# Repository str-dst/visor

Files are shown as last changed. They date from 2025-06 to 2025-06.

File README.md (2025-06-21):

# The digital face of unit 0x4C6F75

Visor based on a cheap modified 3M 6800 clone full face gas mask

## What?

Two "see-through" 16x16 ws2812b LED panels mounted behind the glass of a full face gas mask.
The glass was tinted using Rit-Dyemore Graphite-Black plastic dye to hide the electronics inside.  

The panels are controlled by a relatively simple Python script running on a RPi Zero 2W.  
A wired six-button remote strapped to my left hand is used to change the displayed faces.  
Two of the buttons on the remote act as "modifiers", making a total of 16 combinations possible.  

## How?

The faces are stored as simple 16x32 1-bit black/white bitmap files.  
Every face is mapped to one of the remotes keycodes.  

The image files are first loaded with PIL and the pixel values are stored in a list.  
A preselect color is then added to the "active" white pixels of the loaded image.  
The list of pixel values is then simply displayed on the LED matrix.  

The remote controller is based on an Elite-C controller and hardwired to the Pi via USB.  
For each keypress or keypress-combination a distinctive keycode is sent over a serial connection.  
On key release the code '0x00' is sent, though this has currently no real use.  

Keycode 0x10 is an exception and cycles through different colors for the face.  
Some faces have a preset color that changes automatically for an added effect.  

## Currently implemented codes

 |Keycode|Display content|Color|
 |-|-|-|
 |0x01|Happy, pointy upwards|default|
 |0x02|Wide round eyes|default|
 |0x03|Sleepy drowsy looking|default|
 |0x04|Wink, left eye closed|default|
 |0x05|BOOPED, pointy inward|default|
 |0x06|Dizzy, twirly eyes|purple|
 |0x07|Annoyed, Flat eyes|default|
 |0x08|Focused, Small eyes|default|
 |0x09|Love, Heart eyes|pink|
 |0x0A|Dead, X eyes|red|
 |0x0B|Angry, frowning|red|
 |0x0C|Sad, droopy|blue|
 |0x0D|Text: BEEP|green|
 |0x0E|Text: awoo|orange|
 |0x0F|Text: NO|red|

## Possible additions / changes for the future

 - Add more key combos to the remote to be able to add more faces
 - Make it possible to create "compound faces" individually controlling the left or right eye
 - Adding a "boop sensor" to the nose of the mask
 - A microphone on the inside of the mask and a speaker on the outside for real-time voice changing
 - Eye detection inside the mask to automatically change the face / display a "blink" animation

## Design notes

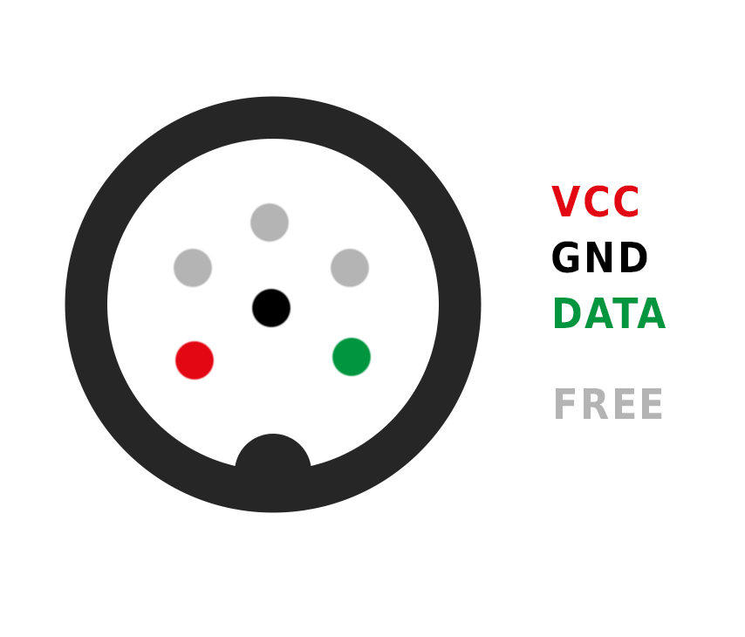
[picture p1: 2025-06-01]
gx12_pinout.png

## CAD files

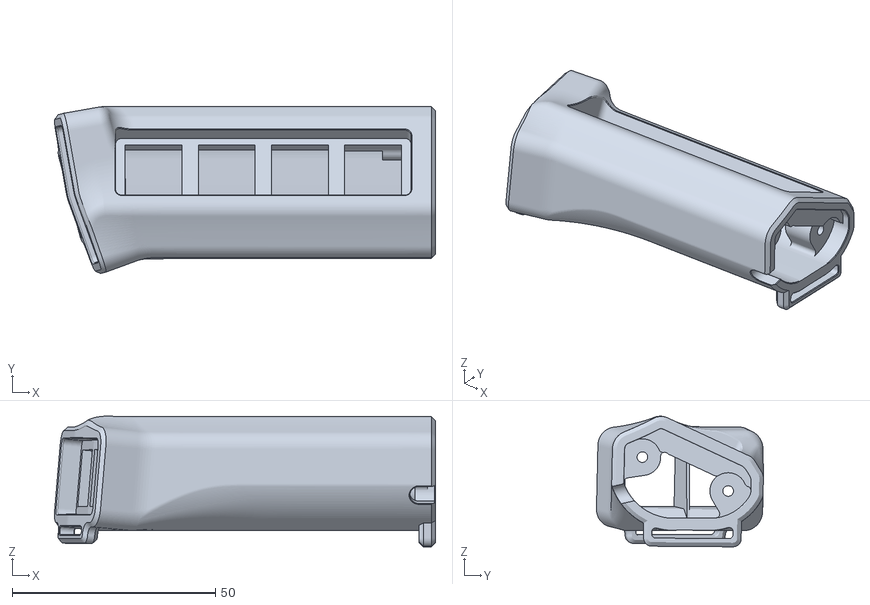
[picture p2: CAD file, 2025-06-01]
stls/remote_body.stl
93.7 x 41.1 x 32.1

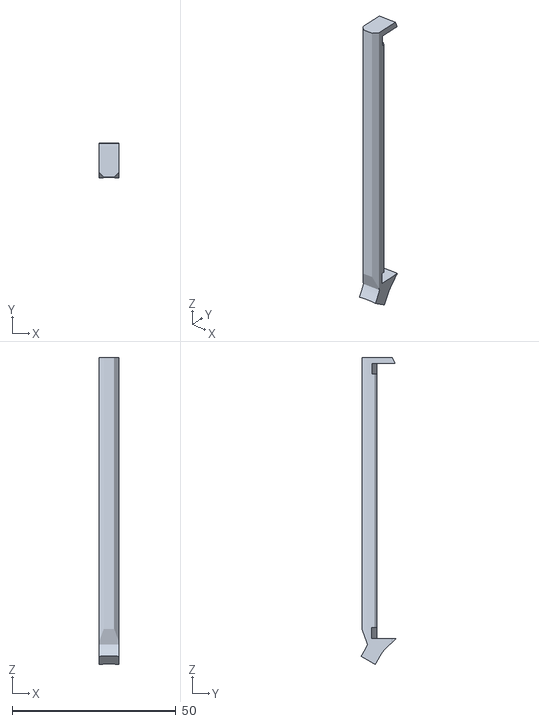
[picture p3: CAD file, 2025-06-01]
stls/display_center_support.stl
6.00 x 10.6 x 93.9

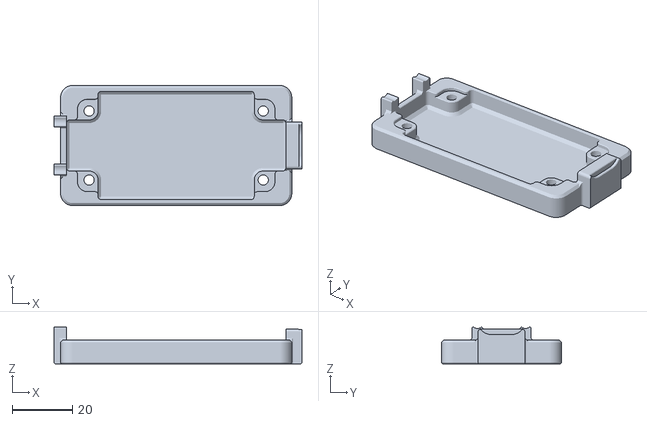
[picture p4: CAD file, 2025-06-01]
stls/rpi_case_bottom.stl
82.6 x 40.0 x 12.3

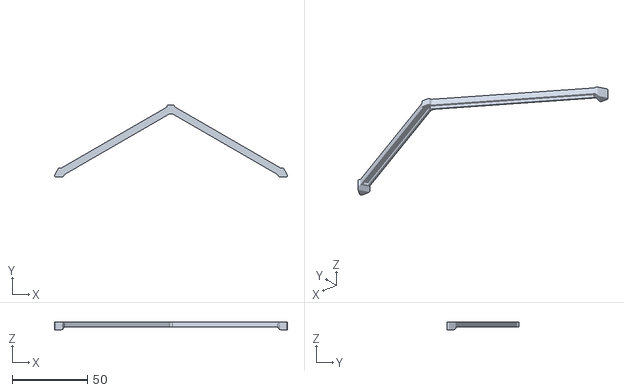
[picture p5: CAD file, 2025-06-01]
stls/display_top_frame.stl
154.7 x 48.1 x 5.00

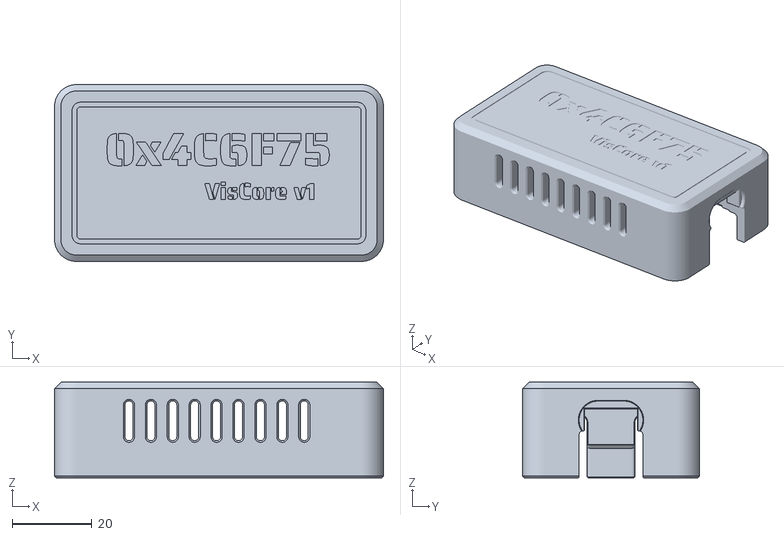
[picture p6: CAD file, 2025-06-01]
stls/rpi_case_top.stl
82.6 x 44.4 x 24.0

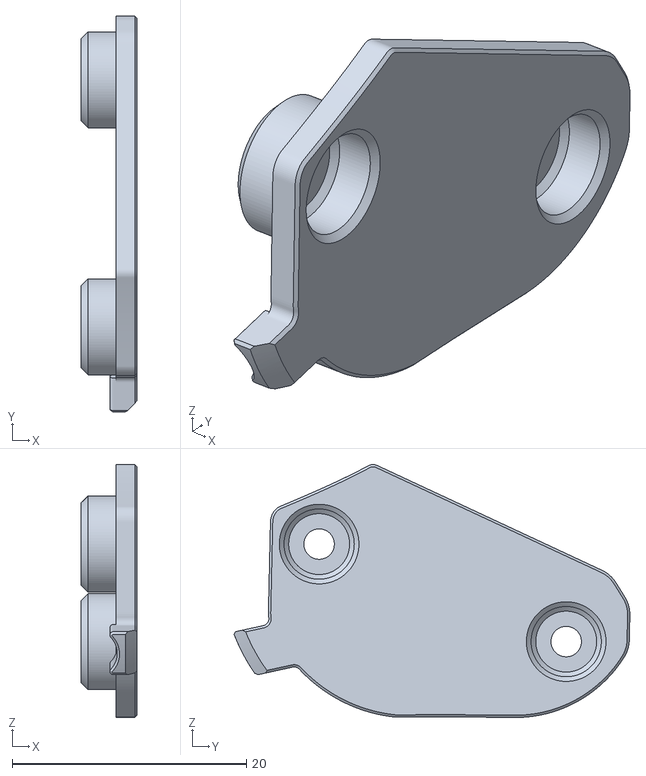
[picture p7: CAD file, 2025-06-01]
stls/remote_lid.stl
4.80 x 33.8 x 21.6

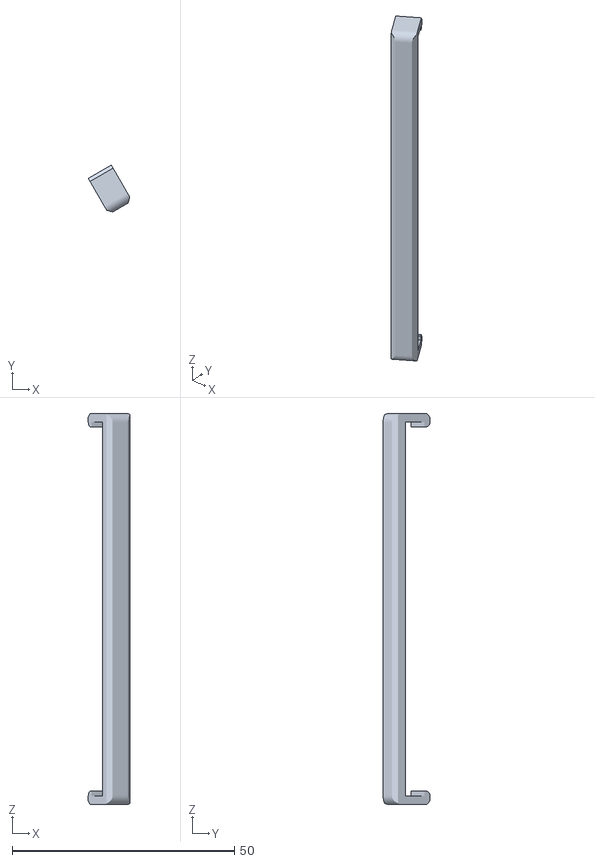
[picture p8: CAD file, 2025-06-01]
stls/display_side_brace.stl
9.35 x 10.6 x 88.0

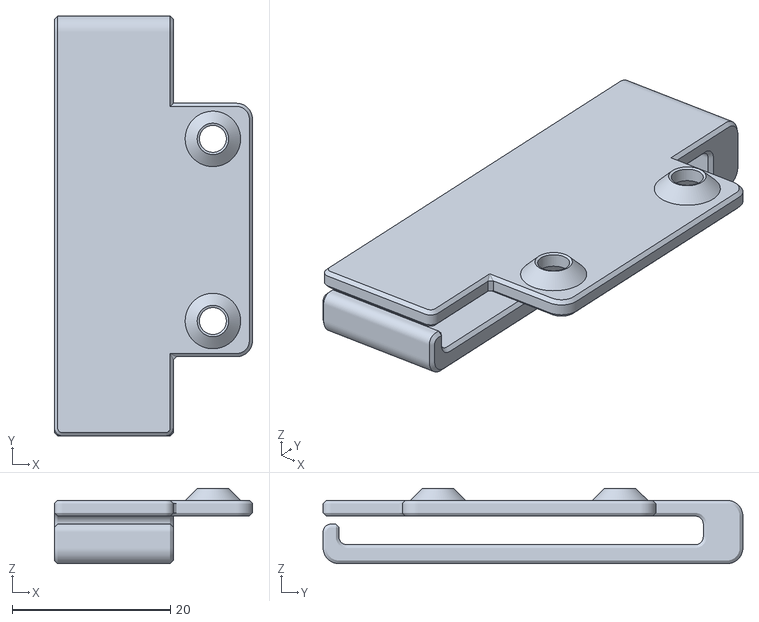
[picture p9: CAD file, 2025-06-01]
stls/rpi_belt_clip.stl
25.0 x 53.0 x 9.52

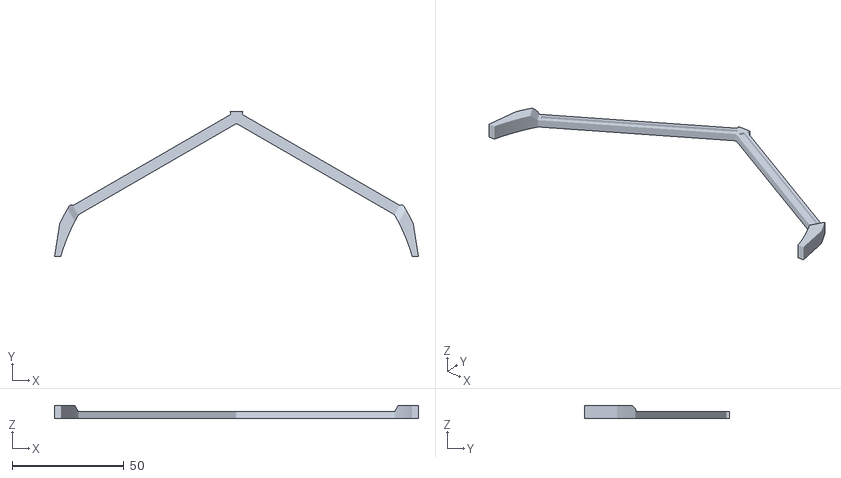
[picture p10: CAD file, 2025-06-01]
stls/display_bottom_frame.stl
162.9 x 65.1 x 6.00

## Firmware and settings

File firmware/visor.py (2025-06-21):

#!/usr/bin/python3

from PIL import Image
import numpy as np
from rpi_ws281x import PixelStrip, Color
import serial
import time

# LED strip configuration:
LED_COUNT = 512      # Number of LED pixels.
LED_PIN = 18         # GPIO pin connected to the pixels (18 uses PWM!).
LED_FREQ_HZ = 800000 # LED signal frequency in hertz (usually 800khz)
LED_DMA = 10         # DMA channel to use for generating signal (try 10)
LED_BRIGHTNESS = 32  # Set to 0 for darkest and 255 for brightest
LED_INVERT = False   # True to invert the signal (when using NPN transistor level shift)
LED_CHANNEL = 0      # set to '1' for GPIOs 13, 19, 41, 45 or 53

# Load and process the bitmap, our matrix is mounted upside down so we rotate the image
def load_and_process_bitmap(image_path):
    img = Image.open(image_path).convert("1")
    img_flip = img.rotate(180)
    bitmap = np.array(img_flip)
    return process_bitmap(bitmap)

# Process the bitmap
def process_bitmap(bitmap):
    height, width = bitmap.shape
    processed_pixels = []

    for col in range(width):
        if col % 2 == 0:
            # Even columns: read from top to bottom
            column_pixels = bitmap[:, col]
        else:
            # Odd columns: read from bottom to top
            column_pixels = bitmap[::-1, col]

        processed_pixels.extend(column_pixels)

    return processed_pixels

# Add color to active white pixels
def add_color(processed_pixels, color):
    colored_pixels = []
    for pixel in processed_pixels:
        if pixel == 1:  # White pixel
            colored_pixels.append(color)
        else:
            colored_pixels.append((0, 0, 0))  # Black pixel
    return colored_pixels

# Display on WS2812B LED matrix
def display_on_led_matrix(pixel_values):
    # Create PixelStrip object with appropriate configuration.
    strip = PixelStrip(LED_COUNT, LED_PIN, LED_FREQ_HZ, LED_DMA, LED_INVERT, LED_BRIGHTNESS, LED_CHANNEL)

    # Initialize the LED panel
    strip.begin()

    # Iterate over each pixel value and set the LED color
    for i, pixel in enumerate(pixel_values):
        if i >= LED_COUNT:
            break  # Ensure we do not exceed the number of LEDs
        # Assuming pixel is in the format (R, G, B)
        strip.setPixelColor(i, Color(pixel[0], pixel[1], pixel[2]))

    # Show the LED colors
    strip.show()

    # Clean up
    time.sleep(0.3)
    strip._cleanup()

# Main function
def main():
    # Mapping of serial data codes to image file paths
    image_mapping = {
        b'\x01': 'faces/01_happy.bmp',
        b'\x02': 'faces/02_wide.bmp',
        b'\x03': 'faces/03_sleepy.bmp',
        b'\x04': 'faces/04_wink.bmp',
        b'\x05': 'faces/05_boop.bmp',
        b'\x06': 'faces/06_dizzy.bmp',
        b'\x07': 'faces/07_flat.bmp',
        b'\x08': 'faces/08_small.bmp',
        b'\x09': 'faces/09_hearts.bmp',
        b'\x0A': 'faces/10_dead.bmp',
        b'\x0B': 'faces/11_angry.bmp',
        b'\x0C': 'faces/12_sad.bmp',
        b'\x0D': 'faces/13_beep.bmp',
        b'\x0E': 'faces/14_awoo.bmp',
        b'\x0F': 'faces/15_no.bmp',
    }

    # Preset color indexes for some of the faces
    color_mapping = {
        b'\x06': 4,
        b'\x09': 5,
        b'\x0A': 6,
        b'\x0B': 6,
        b'\x0C': 2,
        b'\x0D': 0,
        b'\x0E': 7,
        b'\x0F': 6,
    }

    # Color set that we can loop through
    color_values = [
        (0, 255, 0),    # Green
        (0, 255, 128),  # Turquoise
        (0, 64, 255),   # Light blue
        (0, 0, 255),    # Blue
        (48, 0, 255),   # Purple
        (192, 0, 255),  # Pink
        (255, 0, 0),    # Red
        (255, 48, 0),   # Orange
        (255, 192, 0),  # Yellow
        (64, 255, 0),   # Lime
        (255, 255, 255) # White
    ]

    # Define the color index for active white pixels (e.g., red)
    current_color_index = 0
    previous_color_index = 0
    color_was_preset = False

    # Initialize serial connection
    ser = serial.Serial('/dev/ttyACM0', 9600, timeout=1)

    current_image_path = image_mapping[b'\x01']  # Default image

    # Initial display load
    processed_pixels = load_and_process_bitmap(current_image_path)
    colored_pixels = add_color(processed_pixels, color_values[current_color_index])
    display_on_led_matrix(colored_pixels)

    try:
        while True:
            # Read data from serial
            data = ser.read(1)

            if data:
                # Ignore the key-release code for now
                if data == b'\x00':
                    continue

                # Cycle through the preset colors on 0x10
                if data == b'\x10':
                    if current_color_index == 10:
                        current_color_index = 0
                    else:
                        current_color_index += 1
                    previous_color_index = current_color_index

                # All other keycodes check against image and color mapping
                else:
                    if data in color_mapping:
                        if color_was_preset == False:
                            previous_color_index = current_color_index
                        color_was_preset = True
                        current_color_index = color_mapping[data]
                    else:
                        color_was_preset = False
                        current_color_index = previous_color_index

                    if data in image_mapping:
                        current_image_path = image_mapping[data]

                # Print some debug info...
                print("Data recv: "+str(data)+", Image: "+str(current_image_path)+", Color: "+str(current_color_index))

                # Load and process the selected image
                processed_pixels = load_and_process_bitmap(current_image_path)
                colored_pixels = add_color(processed_pixels, color_values[current_color_index])
                display_on_led_matrix(colored_pixels)

    except KeyboardInterrupt:
        print("Exiting...")
    finally:
        ser.close()

# Run the main function
if __name__ == "__main__":
    main()

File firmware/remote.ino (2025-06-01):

// Stupid simple controller for the visor of 0x4C6F75
//
// Published under the unlicense - 2025

// Define the pins for the buttons
const int inputButtonPins[] = {16, 14, 15, 18};
const int modButtonPins[] = {20, 21};

// Define keycodes for input buttons
const int keycodeInput[] = {0x01, 0x02, 0x03, 0x04};

// Define keycodes for modifier combinations
const int keycodeMod1[] = {0x05, 0x06, 0x07, 0x08};
const int keycodeMod2[] = {0x09, 0x0A, 0x0B, 0x0C};
const int keycodeModBoth[] = {0x0D, 0x0E, 0x0F, 0x10};

const int keyUpCode = 0x00;

// Variables to store the previous state of input buttons
bool prevInputButtonStates[] = {HIGH, HIGH, HIGH, HIGH};

void setup() {
  // Initialize serial communication
  Serial.begin(9600);

  // Set button pins as inputs with pull-up resistors
  for (int pin : inputButtonPins) {
    pinMode(pin, INPUT_PULLUP);
  }
  for (int pin : modButtonPins) {
    pinMode(pin, INPUT_PULLUP);
  }
}

void loop() {
  // Read the state of each modifier button
  bool mod1Pressed = digitalRead(modButtonPins[0]) == LOW;
  bool mod2Pressed = digitalRead(modButtonPins[1]) == LOW;

  // Check each input button
  for (int i = 0; i < 4; i++) {
    bool currentState = digitalRead(inputButtonPins[i]);

    // Check if the button was just pressed (transition from HIGH to LOW)
    if (prevInputButtonStates[i] == HIGH && currentState == LOW) {
      // Determine which keycode to send based on modifier buttons
      if (mod1Pressed && mod2Pressed) {
        Serial.write(keycodeModBoth[i]);
      } else if (mod1Pressed) {
        Serial.write(keycodeMod1[i]);
      } else if (mod2Pressed) {
        Serial.write(keycodeMod2[i]);
      } else {
        Serial.write(keycodeInput[i]);
      }
    }
    // Check if the button was just released (transition from LOW to HIGH)
    else if (prevInputButtonStates[i] == LOW && currentState == HIGH) {
      Serial.write(keyUpCode);
    }

    // Update the previous state
    prevInputButtonStates[i] = currentState;
  }

  // Small delay to debounce the buttons
  delay(50);
}

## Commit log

2025-06-01 restructure and add visor code
    [display_bottom_frame.stl, display_center_support.stl, display_side_brace.stl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]
2025-06-02 fix color getting stuck
    [visor.py]
